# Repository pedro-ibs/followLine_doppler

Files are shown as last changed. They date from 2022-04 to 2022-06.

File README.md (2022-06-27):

# followLine_doppler
Robô seguidor de linha doppler  utilizado na competição "RMS CHALLENGE" 04/21-23 de 2022

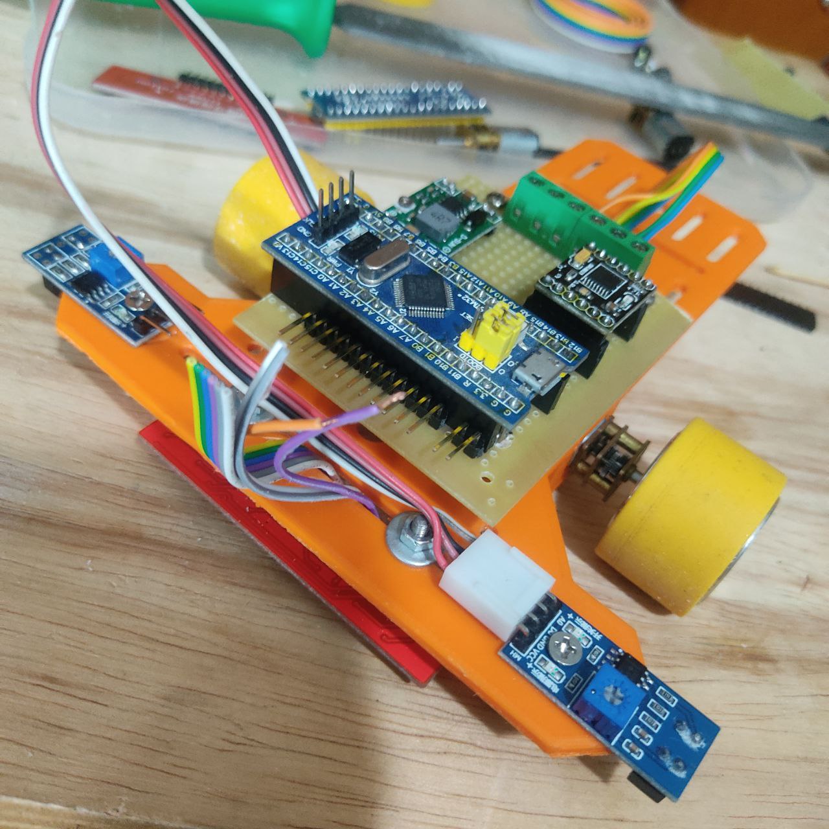
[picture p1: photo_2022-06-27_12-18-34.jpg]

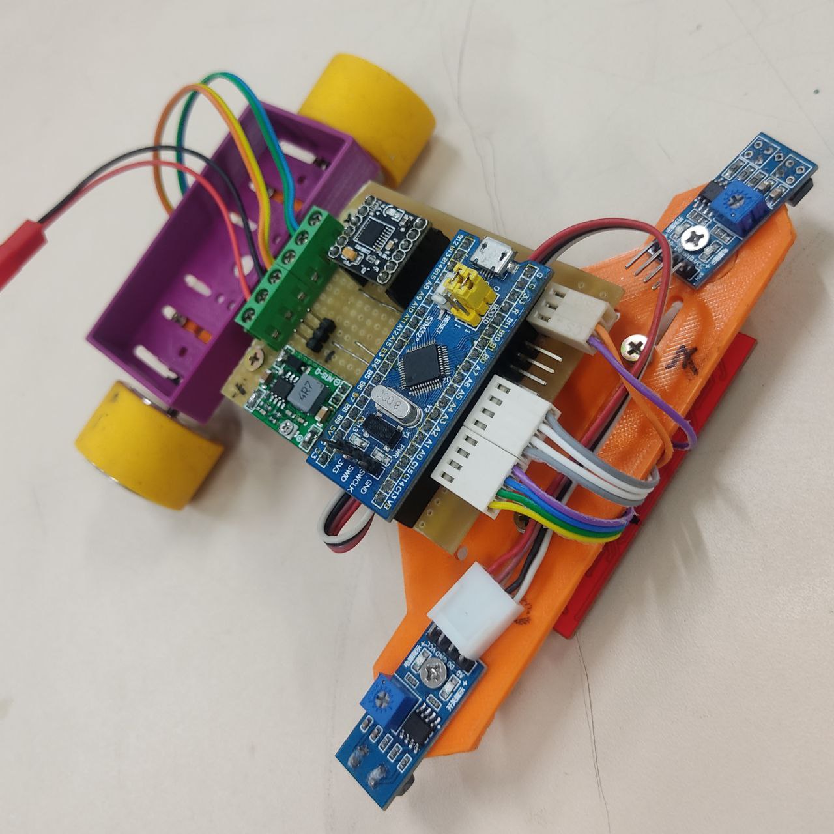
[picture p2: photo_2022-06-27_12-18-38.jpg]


Ele faz uso de um mico controlador stm32f103x na plataforma de desenvolvimento *"bluepill"*. NO  desenvolvimento da firmware foi utilizado o C e o Sistema operacional em tempo real FreeRTOS.

Ela é composta por alguns arquivos importante para a lógica de funcionamento do robô:

<br>

[hardware.h](/firmware/include/hardware.h) Onde são definidos os pinos utilizados, como GPIOs, ADCs etc... 

<br>

[config.h](/firmware/include/config.h) Onde estão configurações globais, como Kp Ki e Kd dos PIDs, valores de cortes das leituras dos ADCs e temporizadores utilizados.

<br>

[pid.h](/firmware/lib/core/FreeRTOS/utility/pid.h) e [pid.c](/firmware/lib/core/FreeRTOS/utility/pid.c), biblioteca para processar o PID, ela abstrai os cálculos do processo. 

<br>

[/motor.h](/firmware/lib/motor/motor.h) e [motor.c](/firmware/lib/motor/motor.c), biblioteca para controle dos motores para pontes H que operam de foram similar ou igual ao LM293D .

<br>

[main_app.c](/firmware/src/main_app.c) Onde a logica de controle ocorre.

## **Funcionamento**

O FreeRTOS é um sistema que opera na vase do tempo e cria treads/tasks para executar as tarefas da aplicação. no caso do robo está sendo utilizado apenas a task principal.

### **Base**

Para realizar as leituras dos sensores cujo o sinal é analógico é utilizado em conjunto o TIMER3, DMA  e os ADCs. Basicamente o sistema realiza aquisições cíclicas em uma taxa de 10kHz por canal, ou seja a cada 0.0001s é realizada a leitura de 8 canais.

As leituras são concluídas após o buffer de memoria alocado estiver cheio, cada canal possui 10 espaços, onde o DMA transfere os valores  lidos do canal para a memoria de forma sequencial. Isso deixa o ciclo completo de leitura dos senores ter 1kHz.

A pós a conclusão das leituras uma interrupção é chamada ( função `void acd1_vBufferDoneHandler(BaseType_t *const pxHigherPriorityTaskWoken)` ), e nela e tratado dodo os cálculos para controlar o robo, isso ocorre de forma cíclica.

<br>

### **Logica de Controle**

**`void main_vApp(void * pvParameters)`**: Onde é inicializado as variáveis e configurado os GPIOs e os periféricos utilizados nas leituras dos sensores e logica da firmware.

**`acd1_vBufferDoneHandler(BaseType_t *const pxHigherPriorityTaskWoken)`**: Onde ocorre as demais etapas do calculo e controle do robô, (NOTA: geralmente essas atividades não ocorrem em interrupções) esse processos são subdivididos em algumas etapas:
  * Limpar variáveis: "`void app_vCleanValues(void)`"
  * Tratamento do sinal: "`void app_vSignalTreatment(void)`"
  * Processamento onde o controle do robo e caculos do pid são executados: "`void app_vProcess(void)`"

**void app_vSignalTreatment(void)**: 

1. Após o DMA concluir o preenchimento do buffer, os dado são acumulados (somados) para cada canal respectivo. Iniciando o processo para calcular do valor médio lido por cada senor (meia móvel).

2. Termino do processo do calculo de media.

3. Transforma os valores lidos pelos sensores em posicionamento onde variam de 0 a 7000 e gradações aproximando se do conceito de uma régua como mostrado abaixo e cada led foto snivel do sensor de linha corresponde a um pondo de S0 a S7:

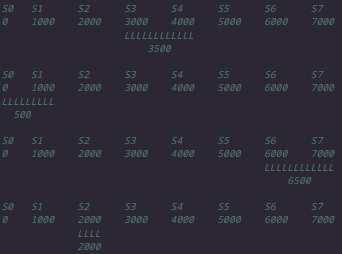
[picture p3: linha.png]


**void app_vProcess(void)**: (documentando, embora haja vários comentários no corpo dessa função )

### **Sobre a mecânica**

O chassi foi feito dessa forma opara permitir alterar a posição dos motores, pois isso afeta no controle do robô quando mais proximo dos pontos de apoio ( roda esférica ) menos força eles terão que fazer para controlar o seguidor, portando ele sera mais rápido assim tendo uma controlei PID mais instável, quando mais longe dos ponto de apoio terá efeito contrario.

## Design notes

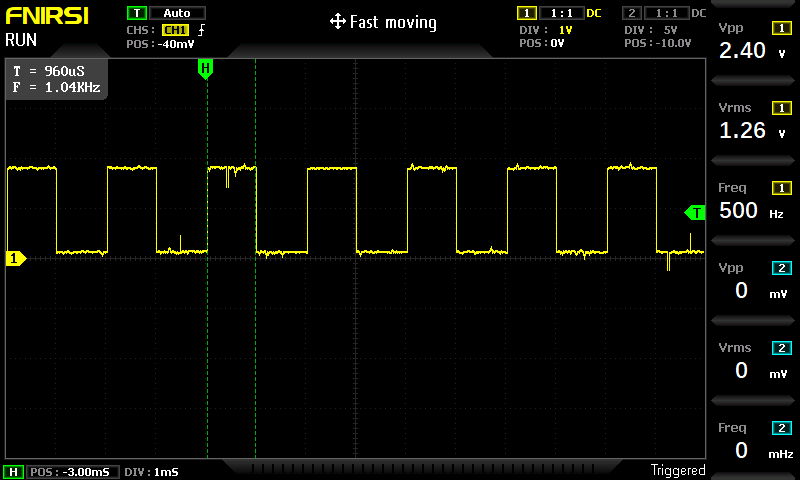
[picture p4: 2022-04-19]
firmware/imd/comCalculos.bmp

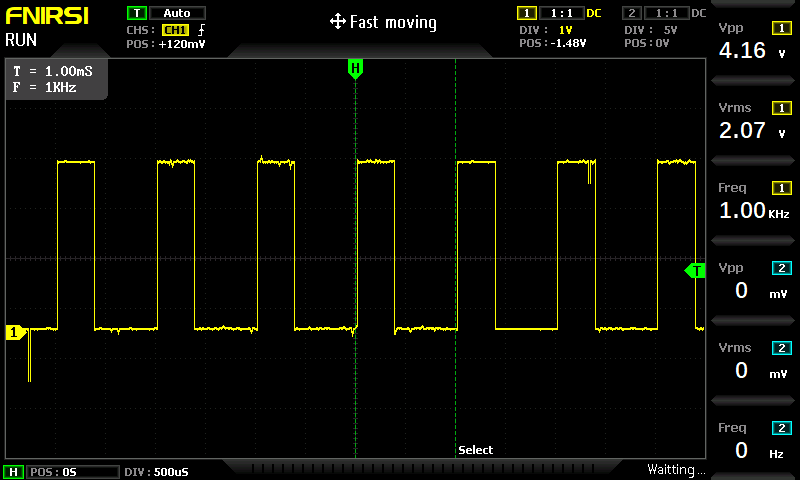
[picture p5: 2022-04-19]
firmware/imd/pwm.bmp

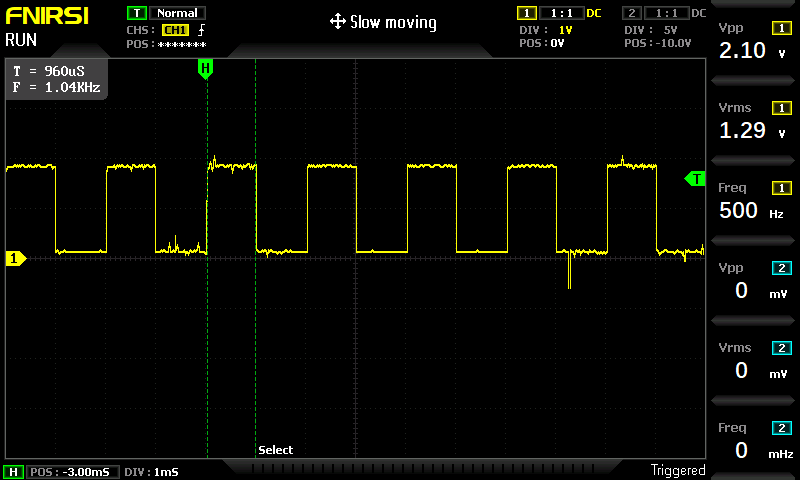
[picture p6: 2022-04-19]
firmware/imd/semCalculos.bmp

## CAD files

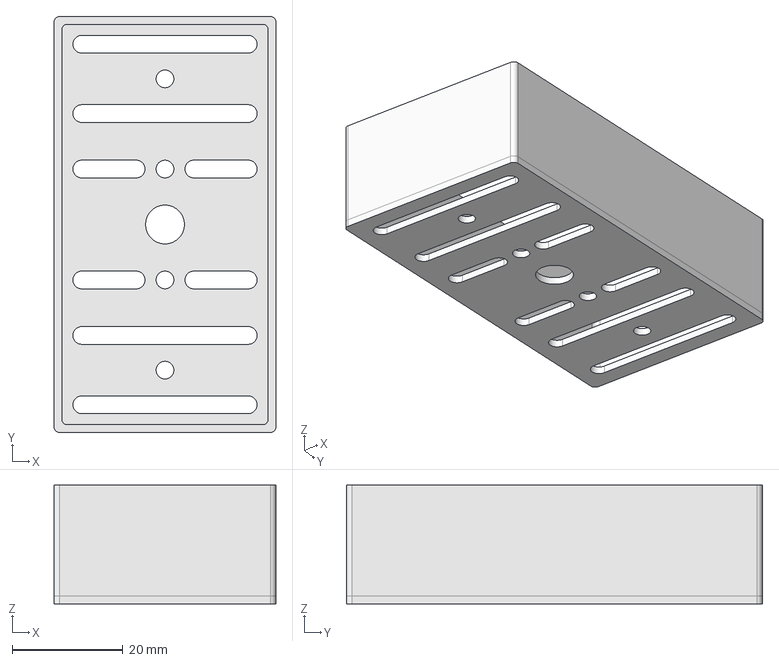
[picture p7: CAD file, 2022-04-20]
freecad/batterySupport.FCStd
40.0 x 75.0 x 21.4 mm

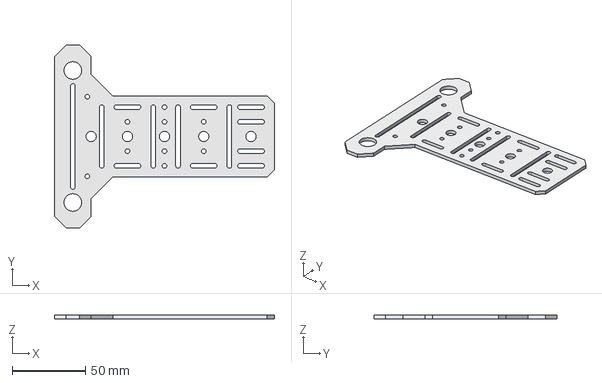
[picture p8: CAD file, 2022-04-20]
freecad/chassi.FCStd
150.0 x 125.0 x 2.50 mm

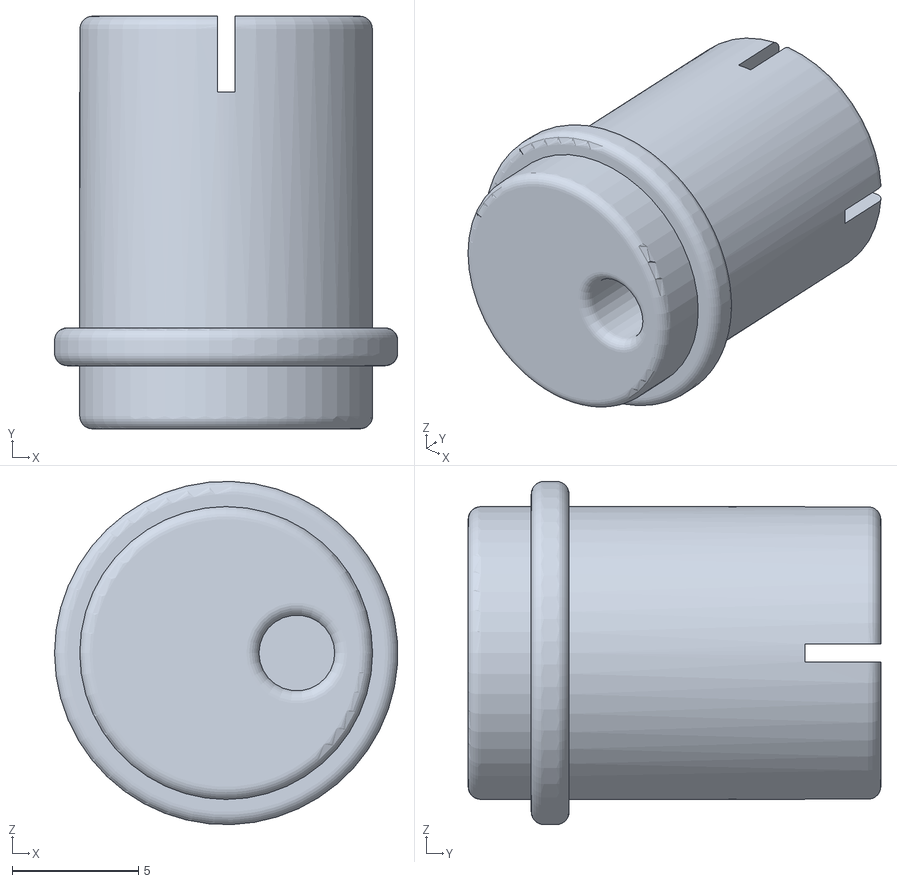
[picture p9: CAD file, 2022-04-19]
freecad/stl/sphericalWheelSupport-Body.stl
13.6 x 16.4 x 13.6

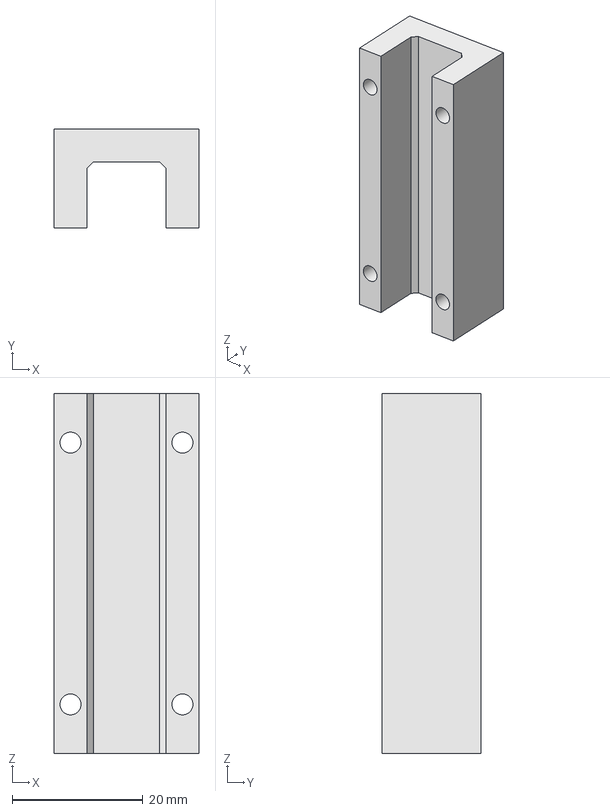
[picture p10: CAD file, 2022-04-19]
freecad/motorFixation.FCStd
22.1 x 15.1 x 55.0 mm

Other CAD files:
freecad/stl/batterySupport-Body.stl
freecad/sphericalWheelSupport.FCStd
freecad/stl/chassi-Body.stl
freecad/stl/motorFixation-Body.stl

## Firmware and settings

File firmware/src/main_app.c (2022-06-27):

/**
 * main_app.h
 *
 *  @date Created at:	13/04/2022 19:30:36
 *	@author:	Pedro Igor B. S.
 *	@email:		pedro.igor.ifsp@gmail.com
 * 	GitHub:		https://github.com/pedro-ibs
 * 	tabSize:	8
 *
 * #######################################################################
 *
 *   Copyright (C) Pedro Igor B. S 2021
 * -------------------------------------------------------------------
 *
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
 * Esse é um programa dedicado ao controle do robô seguidor de linha doppler
 * utilizado na competição "RMS CHALLENGE" 04/21-23 de 2022
 * 
 * A aplicação utiliza o FreeRTOS e drivers para ter acesso aos recursos
 * da CPU
 * 
 * Para a litura dos sensores é utilizado o DMA
 * Para a execução do controle PID e atuação dos motores é utilizado a
 * interrupção do DMA
 * 
 * Em config.h e hardware.h estão as definições de hardware e configurações
 * da aplicação 
 * 
 */



/* Includes ---------------------------------------------------------------------------------------------------------------------------------------------*/
#include <core.h>
#include <FreeRTOS/includes.h>
#include <config.h>
#include <hardware.h>
#include <motor.h>
/* Local macro ------------------------------------------------------------------------------------------------------------------------------------------*/
#define LINE_FULL_DETECTED	(spuAverage[0] < scpuLineDetected[0]) && (spuAverage[7] < scpuLineDetected[7])
/* Local variables --------------------------------------------------------------------------------------------------------------------------------------*/
typedef struct {
	Motor xMotor;
	float fPwm;
}MotorTask;

static const u16 scpuLineDetected[SAMPLES]	= {
	LINE_DETECTED_0,
	LINE_DETECTED_1,
	LINE_DETECTED_2,
	LINE_DETECTED_3,
	LINE_DETECTED_4,
	LINE_DETECTED_5,
	LINE_DETECTED_6,
	LINE_DETECTED_7
};

static const short int scpuLineValue[SAMPLES]	= {
	LINE_VALUE_0,
	LINE_VALUE_1,
	LINE_VALUE_2,
	LINE_VALUE_3,
	LINE_VALUE_4,
	LINE_VALUE_5,
	LINE_VALUE_6,
	LINE_VALUE_7
};

static u16 spuAdc1Buffer[BUFFER_SIZE]		= { 0 };
static u16 spuAverage[CHANNELS]			= { 0 };
static MotorTask sxMa 				= { { MOTOR_M1A1_PWM, MOTOR_M1A2_PWM }, PWM_MIN };
static MotorTask sxMb 				= { { MOTOR_M2A1_PWM, MOTOR_M2A2_PWM }, PWM_MIN };
static Pid sxPid				= { 0 };
static u16 uPosition				= 0;
static TickType_t sxIgnoreStop			= 0;
static TickType_t sxToStop			= 0;

/* Local Functions --------------------------------------------------------------------------------------------------------------------------------------*/
void motor_vTask(void * pvParameters);
void app_vSignalTreatment(void);
void app_vCleanValues( void );
void app_vProcess( void );
/* Functions --------------------------------------------------------------------------------------------------------------------------------------------*/


/*########################################################################################################################################################*/
/*########################################################################################################################################################*/
/*########################################################################################################################################################*/
/*-------------------------------------------------------------------- Local Functions -------------------------------------------------------------------*/
/*########################################################################################################################################################*/

/**
 * Apos as configurações de hardware e valores de variáveis, Essa só irá  task existir
 * para realizar o "debug", caso APP_DEBUG não for definido ela será desativada (deletada).
 * 
 * veja em platformio.ini
 */
void main_vApp(void * pvParameters){
	(void) pvParameters;

	vTaskDelay(_5S);

	sxPid.fSetPoint = PID_SETPOINT;
	sxPid.fKp 	= PID_KP;
	sxPid.fKi 	= PID_KI;
	sxPid.fKd 	= PID_KD;


	/**
	 * ignora o stop na partida por 10 segundos já na partida há um cursamento 
	 * evitando que o robô pare logo no inicio
	 */
	sxIgnoreStop	= 10000;

	gpio_vInitAll(  );
	gpio_vDisableDebug ( );

	gpio_vMode( LED,	GPIO_MODE_OUTPUT_OD,	GPIO_PULLDOWN );
	gpio_vMode( LINE_STOP,	GPIO_MODE_INPUT,	GPIO_PULLDOWN );
	gpio_vMode( LINE_CURVE,	GPIO_MODE_INPUT,	GPIO_PULLDOWN );

	pwm_vSetGpio( MOTOR_M1A1 );
	pwm_vSetGpio( MOTOR_M1A2 );
	pwm_vSetGpio( MOTOR_M2A1 );
	pwm_vSetGpio( MOTOR_M2A2 );

	
	pwm_vSetup( TIM1, PWM_PRESCALER, PWM_PERIOD );
	motor_vToStop( PWM_MAX, &sxMa.xMotor );
	motor_vToStop( PWM_MAX, &sxMb.xMotor );

	adc1_vInit();
	adc1_vSetGetSampleMode( CHANNELS );
	adc1_vSetChannel( LINE_0, ADC_SAMPLETIME, ADC_REGULAR_RANK_1	);
	adc1_vSetChannel( LINE_1, ADC_SAMPLETIME, ADC_REGULAR_RANK_2	);
	adc1_vSetChannel( LINE_2, ADC_SAMPLETIME, ADC_REGULAR_RANK_3	);
	adc1_vSetChannel( LINE_3, ADC_SAMPLETIME, ADC_REGULAR_RANK_4	);
	adc1_vSetChannel( LINE_4, ADC_SAMPLETIME, ADC_REGULAR_RANK_5	);
	adc1_vSetChannel( LINE_5, ADC_SAMPLETIME, ADC_REGULAR_RANK_6	);
	adc1_vSetChannel( LINE_6, ADC_SAMPLETIME, ADC_REGULAR_RANK_7	);
	adc1_vSetChannel( LINE_7, ADC_SAMPLETIME, ADC_REGULAR_RANK_8	);


	/**
	 * A frequência de aquisição é de 10kHz, onde os
	 * canais são lidos 10 vezes antes de chamar a
	 * interrupção do DAM dessa forma ela irá ocorrer
	 * a cada 1ms  (1kHz).
	 */
	adc1_vStartGetSampleMode( spuAdc1Buffer, BUFFER_SIZE, PRESCALER, PERIOD );


	#ifdef APP_DEBUG
		char pcString[10] = "0";
	#endif

	while (TRUE) {
		#ifdef APP_DEBUG
			usart_vAtomicSendStr(ttyUSART1, "MA: ");
			usart_vAtomicSendStr(ttyUSART1, textp_pcCharLeft(itoa(sxPid.fSetPoint,	pcString, DEC), 4, ' '));
			usart_vAtomicSendStr(ttyUSART1, ", ");
			usart_vAtomicSendStr(ttyUSART1, textp_pcCharLeft(itoa(uPosition,	pcString, DEC), 4, ' '));
			usart_vAtomicSendStr(ttyUSART1, ", ");
			usart_vAtomicSendStr(ttyUSART1, textp_pcCharLeft(itoa(sxPid.fError,	pcString, DEC), 4, ' '));
			usart_vAtomicSendStr(ttyUSART1, ", ");
			usart_vAtomicSendStr(ttyUSART1, textp_pcCharLeft(itoa(sxPid.fOutput,	pcString, DEC), 4, ' '));
			usart_vAtomicSendStr(ttyUSART1, ", ");
			usart_vAtomicSendStr(ttyUSART1, textp_pcCharLeft(itoa(sxMa.fPwm,	pcString, DEC), 4, ' '));
			usart_vAtomicSendStr(ttyUSART1, ", ");
			usart_vAtomicSendStr(ttyUSART1, textp_pcCharLeft(itoa(sxMb.fPwm,	pcString, DEC), 4, ' '));
			usart_vAtomicSendStr(ttyUSART1, "\r\n" );
		#else
			break;
		#endif

		/**
		 * esse delay é necessário para evitar starvation
		 */
		vTaskDelay(_20MS);
	}

	vTaskDelete(NULL);
}


void app_vCleanValues( void ){
	for (u8 uChannel = 0; uChannel < CHANNELS; uChannel++) {
		spuAverage[uChannel] = 0;
	}
	uPosition = 0;
}

/**
 * 1 ) Após o DMA concluir o preenchimento do buffer, os dado
 * são acumulados (somados) para cada canal respectivo.
 * iniciando o processo para calcular do valor médio lido por
 * cada senor.
 * 
 * 2 ) Termino do processo do calculo de media.
 * 
 * 3 ) Transforma os valores lidos pelos sensores em posicionamento
 * onde variam de 0 a 7000 e gradações como mostrado abaixo:
 * 
 * 
 * S0	S1	S2	S3	S4	S5	S6	S7
 * 0	1000	2000	3000	4000	5000	6000	7000
 * 			LLLLLLLLLLLL
 * 			    3500
 * 
 * S0	S1	S2	S3	S4	S5	S6	S7
 * 0	1000	2000	3000	4000	5000	6000	7000
 * LLLLLLLLL
 *   500
 * 
 * S0	S1	S2	S3	S4	S5	S6	S7
 * 0	1000	2000	3000	4000	5000	6000	7000
 * 						LLLLLLLLLLLL
 * 						    6500
 * 
 * S0	S1	S2	S3	S4	S5	S6	S7
 * 0	1000	2000	3000	4000	5000	6000	7000
 *		LLLL
 *		2000
 */
void app_vSignalTreatment( void ){
	for (u8 uSample = 0; uSample < SAMPLES; uSample++) {
		for (u8 uChannel = 0; uChannel < CHANNELS; uChannel++) {
			spuAverage[uChannel] += spuAdc1Buffer[ ( uSample * CHANNELS ) + uChannel ];
		}
	}

	for (u8 uChannel = 0; uChannel < CHANNELS; uChannel++) {
		spuAverage[uChannel] = (spuAverage[uChannel] / SAMPLES );
	}

	u8 uContDetection = 0;
	for (u8 uChannel = 0; uChannel < CHANNELS; uChannel++) {
		if(spuAverage[uChannel] < scpuLineDetected[uChannel]){
			uContDetection++;

			/**
			 * Manter Valor máximo detectado
			 */
			uPosition = ( scpuLineValue[uChannel]  );

			/**
			 * Criar gradação intermediaria
			 */
			if(uContDetection > 1){
				uPosition -= ( LINE_VALUE_1 / 2 );
			}
		};
	}
}


void app_vProcess( void ){

	/**
	 * após a detecção da linha de chegada o robô irá parara 
	 * apos um certo período de tempo, fazendo com que o mesmo
	 * pere após a linha de chegada.  
	 */
	if(sxToStop > 0){
		/**
		 * O overchute do controle pode fazer com que o robô
		 * trave em cima de um cruzamento para evitar isso é 
		 * verificado se a fixa está embaixo do sensor 
		 */
		if( ( LINE_FULL_DETECTED ) == TRUE ){
			sxToStop = 0;
		}

		/**
		 * indica que o robô está travado 
		 */
		gpio_vWrite(LED, FALSE);


		if( xTaskGetTickCountFromISR() > sxToStop ){
			sxMa.fPwm = PWM_MAX;
			sxMb.fPwm = PWM_MAX;	

			motor_vToStop(sxMa.fPwm, &sxMa.xMotor);
			motor_vToStop(sxMb.fPwm, &sxMb.xMotor);

			return;
		}

	}

	/**
	 * Se todos os sensores estão ativos o robô está
	 * em um cruzamento portanto o stop deve ser ignorado
	 * por um tempo, e o robô deve continuar indo para
	 * frente.
	 */
	if( LINE_FULL_DETECTED ){
		sxIgnoreStop	= xTaskGetTickCountFromISR() + IGNORE_STOP;
		sxToStop	= 0;
		sxMa.fPwm 	= PWM_OFFSET;
		sxMb.fPwm 	= PWM_OFFSET;	

		motor_vToFront(sxMa.fPwm, &sxMa.xMotor);
		motor_vToFront(sxMb.fPwm, &sxMb.xMotor);

		return;
	}
	
	/**
	 * Quando faixa de chagada for detectada o robô
	 * iár travar os motores e "desabilitar/ignorar" 
	 * o controle pid PID, pro meio de um "ponto de
	 * fuga" no inicio da função.
	 */
	if(sxIgnoreStop < xTaskGetTickCountFromISR()){
		if(gpio_bRead(LINE_STOP) == FALSE){
			sxToStop	= WAIT_TO_STOP + xTaskGetTickCountFromISR();
			return;
		}
	}


	/**
	 * Entrada do controle PID
	 */
	sxPid.fInput = uPosition;
	sxPid.fOutput =  pid_fRunFromISR(&sxPid);

	if(uPosition < PID_SETPOINT){
		sxMa.fPwm = PWM_OFFSET + abs(sxPid.fOutput);
		sxMb.fPwm = PWM_OFFSET - abs(sxPid.fOutput);
	} else if(uPosition > PID_SETPOINT){
		sxMa.fPwm = PWM_OFFSET - abs(sxPid.fOutput);
		sxMb.fPwm = PWM_OFFSET + abs(sxPid.fOutput);
	} else {
		sxMa.fPwm = PWM_OFFSET;
		sxMb.fPwm = PWM_OFFSET;
	}


	/**
	 * Tratar valores do PWM para evitar que ultrapasse
	 * o limite configurado no periférico
	 */
	if(sxMa.fPwm > PWM_MAX ){
		sxMa.fPwm = PWM_MAX;	
	}

	if(sxMa.fPwm < PWM_MIN ){
		sxMa.fPwm = PWM_MIN;	
	}

	if(sxMb.fPwm > PWM_MAX ){
		sxMb.fPwm = PWM_MAX;	
	}

	if(sxMb.fPwm < PWM_MIN ){
		sxMb.fPwm = PWM_MIN;	
	}

	/**
	 * ! CONTROLE ON OFF
	 * Os sensores mais extremos ( S0, S7 ) estão atrelados ao  controle
	 * ON OFF isso foi utilizado para evitar que o robô perdesse a linha
	 * em uma curva.
	 * 
	 * Os outros senhores  S1, S2, S3, S4, S5, S6 foram mantido no controle
	 * PID, porem esse controle é ignorado quando o ON OFF está ativo
	 */
	if( (spuAverage[0] < scpuLineDetected[0]) ){
		sxMa.fPwm = PWM_MAX;
		sxMb.fPwm = PWM_MAX;
		motor_vToFront(sxMa.fPwm, &sxMa.xMotor);
		motor_vToStop(sxMb.fPwm, &sxMb.xMotor);
		return;
	}

	if( (spuAverage[7] < scpuLineDetected[7]) ){
		sxMa.fPwm = PWM_MAX;
		sxMb.fPwm = PWM_MAX;
		motor_vToStop(sxMa.fPwm, &sxMa.xMotor);
		motor_vToFront(sxMb.fPwm, &sxMb.xMotor);
		return;
	}

	/**
	 * Isso é apenas um recurso para facilitar nos testes em uma pista.
	 * ao perder a linha completamente o motores são desligados
	 */
	if (uPosition == 0){
		if((spuAverage[0] < scpuLineDetected[0]) == FALSE){
			motor_vTurnoff(&sxMa.xMotor);
			motor_vTurnoff(&sxMb.xMotor);
			return;
		}
	}


	motor_vToFront(sxMa.fPwm, &sxMa.xMotor);
	motor_vToFront(sxMb.fPwm, &sxMb.xMotor);
}

void acd1_vBufferDoneHandler(BaseType_t *const pxHigherPriorityTaskWoken){
	(void) pxHigherPriorityTaskWoken;

	app_vCleanValues();

	app_vSignalTreatment();

	app_vProcess();

	gpio_vToggle(LED);
}


void adc1_vDMA1Ch1Handler(BaseType_t *const pxHigherPriorityTaskWoken){
	(void) pxHigherPriorityTaskWoken;
}

void tim3_vHandler(BaseType_t *const pxHigherPriorityTaskWoken){
	(void) pxHigherPriorityTaskWoken;

}

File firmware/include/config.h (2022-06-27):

/**
 * config.h
 *
 *  @date Created at:	13/04/2022 19:27:34
 *	@author:	Pedro Igor B. S.
 *	@email:		pedro.igor.ifsp@gmail.com
 * 	GitHub:		https://github.com/pedro-ibs
 * 	tabSize:	8
 *
 * #######################################################################
 *
 *   Copyright (C) Pedro Igor B. S 2021
 * -------------------------------------------------------------------
 *
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
 *
 * configurações da aplicação
 *
 */

/* Includes ---------------------------------------------------------------------------------------------------------------------------------------------*/
#include "hardware.h"
#include "FreeRTOS/include/FreeRTOSConfig.h"

#ifndef config_H_
#define config_H_

/* macro -------------------------------------------------------------------------------------------------------------------------------------------------*/
/* Definition --------------------------------------------------------------------------------------------------------------------------------------------*/


/*--------------------------------------------------------------------------------------------------------------------------------------------------------*/
/* Configuração para aquisição e tratamento dos sinais analógicos											  */
/*--------------------------------------------------------------------------------------------------------------------------------------------------------*/
#define CHANNELS			( 8							)
#define SAMPLES				( 10 							)
#define BUFFER_SIZE			( CHANNELS * SAMPLES 					)


#define FREQUENCY			( 1000							)
#define PRESCALER			( 1							)
#define PERIOD				( FREG_TO_COUNTER( FREQUENCY*SAMPLES, PRESCALER )	)
#define ADC_SAMPLETIME			( ADC_SAMPLETIME_71CYCLES_5				)

#define LINE_DETECTED_0			( 3500							)
#define LINE_DETECTED_1			( 3500							)
#define LINE_DETECTED_2			( 3500							)
#define LINE_DETECTED_3			( 3500							)
#define LINE_DETECTED_4			( 3500							)
#define LINE_DETECTED_5			( 3500							)
#define LINE_DETECTED_6			( 3500							)
#define LINE_DETECTED_7			( 3500							)


#define LINE_VALUE_0			( 1000 * 0						)
#define LINE_VALUE_1			( 1000 * 1						)
#define LINE_VALUE_2			( 1000 * 2						)
#define LINE_VALUE_3			( 1000 * 3						)
#define LINE_VALUE_4			( 1000 * 4						)
#define LINE_VALUE_5			( 1000 * 5						)
#define LINE_VALUE_6			( 1000 * 6						)
#define LINE_VALUE_7			( 1000 * 7						)



/*--------------------------------------------------------------------------------------------------------------------------------------------------------*/
/* Configuração para controle de valosidade														  */
/*--------------------------------------------------------------------------------------------------------------------------------------------------------*/
#define PWM_PRESCALER			( 72-1							)
#define PWM_PERIOD			( 1000-1						)
#define PWM_MAX				( 1000							)
#define PWM_MIN				( 0							)
#define PWM_OFFSET			( PWM_MAX * 0.75					)


#define PID_KP				( 0.75							)
#define PID_KI				( 0.01							)
#define PID_KD				( 0.075							)
#define PID_SETPOINT			( LINE_VALUE_4 - ( LINE_VALUE_1 / 2 )			)


/*--------------------------------------------------------------------------------------------------------------------------------------------------------*/
/* Configuração ferais de tempo																  */
/*--------------------------------------------------------------------------------------------------------------------------------------------------------*/
#define IGNORE_STOP			( 1000 							)
#define WAIT_TO_STOP			( 1000							)

#endif /* config_H_ */

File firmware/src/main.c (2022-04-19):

/**
 * main.c.c
 *
 *  @date Created at:	13/07/2021 13:19:19
 *	@author:	Pedro Igor B. S.
 *	@email:		pibscontato@gmail.com
 * 	GitHub:		https://github.com/pedro-ibs
 * 	tabSize:	8
 *
 * #################################################################################
 * 
 * FreeRTOS Kernel V10.2.1
 * Copyright (C) 2019 Amazon.com, Inc. or its affiliates.  All Rights Reserved.
 *
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
 * http://www.FreeRTOS.org
 * http://aws.amazon.com/freertos
 *
 * 1 tab == 8 spaces!
 * 
 * #################################################################################
 *
 * comtem os handlres do FreeRTOS e inicia o sistema operacionão e deus drivers  e a
 * task principal da aplicação
 *
 */



/* Includes ---------------------------------------------------------------------------------------------------------------------------------------------*/
/* Standard includes. */
#include <string.h>
#include <stdio.h>
#include <stdint.h>
#include <stdlib.h>

/* stm standard includes.  */
#include <core.h>


/* FreeRTOS standard includes.  */
#include <FreeRTOS/includes.h>

/* Private macro ----------------------------------------------------------------------------------------------------------------------------------------*/
/* Private variables ------------------------------------------------------------------------------------------------------------------------------------*/
/* Private Functions ------------------------------------------------------------------------------------------------------------------------------------*/
static void svSetup( void );
static void svSystemClockConfig(void);
static void svAppMainInit(void * pvParameters);
/* Functions --------------------------------------------------------------------------------------------------------------------------------------------*/


int main( void ) {
	#ifdef DEBUG
	debug();
	#endif

	vTaskSuspendAll();
	
	svSetup();
	
	if( xTaskCreate( svAppMainInit, "app_init", configAPP_MAIN_STACK, NULL, tskIDLE_PRIORITY, NULL ) != pdPASS){
		NVIC_SystemReset();
	}

	xTaskResumeAll();

	/* Start the scheduler. */
	vTaskStartScheduler();

	/**
	 * Will only get here if there was insufficient memory to create the idle
	 * task.  The idle task is created within vTaskStartScheduler().
	 */
	for( ;; );

	return 0;
}

/*########################################################################################################################################################*/
/*########################################################################################################################################################*/
/*########################################################################################################################################################*/
/*-------------------------------------------------------------------- Private Functions -----------------------------------------------------------------*/
/*########################################################################################################################################################*/


/**
 * @brief configuração base hardware do microcontrolador 
 * e clock
 */
static void svSetup( void ) {
	SystemCoreClockUpdate();
	HAL_Init();
	svSystemClockConfig();
	HAL_RCC_EnableCSS();

	// FLASH_OB_Unlock();
	// FLASH_OB_RDPConfig( OB_RDP_Level_1 );
	// if (FLASH_OB_Launch() != FLASH_COMPLETE)
	// {
	//     err_printf("Error enabling RDP\n");
	// }
	// FLASH_OB_Lock();
}

void svSystemClockConfig(void) {
	
	/**
	 * Initializes the RCC Oscillators according to the specified parameters
	 * in the RCC_OscInitTypeDef structure.
	 */
	RCC_OscInitTypeDef RCC_OscInitStruct 	= {0};
	RCC_OscInitStruct.OscillatorType	= RCC_OSCILLATORTYPE_LSI|RCC_OSCILLATORTYPE_HSE;
	RCC_OscInitStruct.HSEState		= RCC_HSE_ON;
	RCC_OscInitStruct.HSEPredivValue	= RCC_HSE_PREDIV_DIV1;
	RCC_OscInitStruct.HSIState		= RCC_HSI_ON;
	RCC_OscInitStruct.LSIState		= RCC_LSI_ON;
	RCC_OscInitStruct.PLL.PLLState		= RCC_PLL_ON;
	RCC_OscInitStruct.PLL.PLLSource		= RCC_PLLSOURCE_HSE;
	RCC_OscInitStruct.PLL.PLLMUL		= RCC_PLL_MUL9;
	if (HAL_RCC_OscConfig(&RCC_OscInitStruct) != HAL_OK) {
		Error_Handler();
	}

	/**
	 * Initializes the CPU, AHB and APB buses clocks
	 */
	RCC_ClkInitTypeDef RCC_ClkInitStruct	= {0};
	RCC_ClkInitStruct.ClockType		= RCC_CLOCKTYPE_HCLK|RCC_CLOCKTYPE_SYSCLK|RCC_CLOCKTYPE_PCLK1|RCC_CLOCKTYPE_PCLK2;
	RCC_ClkInitStruct.SYSCLKSource		= RCC_SYSCLKSOURCE_PLLCLK;
	RCC_ClkInitStruct.AHBCLKDivider		= RCC_SYSCLK_DIV1;
	RCC_ClkInitStruct.APB1CLKDivider	= RCC_HCLK_DIV2;
	RCC_ClkInitStruct.APB2CLKDivider	= RCC_HCLK_DIV1;
	if (HAL_RCC_ClockConfig(&RCC_ClkInitStruct, FLASH_LATENCY_2) != HAL_OK){
		Error_Handler();
	}
	
	/**
	 * Ativa o RCC do RTC
	 * Configurar o Clock do ADC1 em 12Mhz
	 */
	RCC_PeriphCLKInitTypeDef PeriphClkInit = {0};
	PeriphClkInit.PeriphClockSelection 		= RCC_PERIPHCLK_RTC|RCC_PERIPHCLK_ADC;
	PeriphClkInit.RTCClockSelection			= RCC_RTCCLKSOURCE_LSI;
	PeriphClkInit.AdcClockSelection 		= RCC_ADCPCLK2_DIV6;
	if (HAL_RCCEx_PeriphCLKConfig(&PeriphClkInit) != HAL_OK) {
		Error_Handler();
	}

}


/**
 * @brief pré inicia drivers de uso geral 
 * 
 */
static void svAppMainInit(void * pvParameters){
	(void) pvParameters;
	
	rtc_vInit();

	iwdg_vInit();

	flash_vInit();

	gpio_vInitAll();

	adc1_vInit();

	swap_vSetup();

	#ifndef DEBUG
	gpio_vDisableDebug();
	#endif

	usart_vSetup(ttyUSART1, usart_19k2bps);

	vTaskDelay(_200MS);
	
	#ifdef APP_DEBUG
	usart_vAtomicSendStrLn(ttyUSART1, "\r\nFreeRTOS Started!");
	#endif

	if( xTaskCreate( main_vApp, "app_main", configAPP_MAIN_STACK, NULL, tskIDLE_PRIORITY, NULL ) != pdPASS){
		NVIC_SystemReset();
	}

	vTaskDelete(NULL);
}
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

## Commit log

2022-04-19 doppler 1.0
    [fixador-Body001.stl, fixador.FCStd, rodaEsferica-Body.stl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]
2022-04-19 update doc and PID
2022-04-19 update pid
2022-04-20 arrumando peças 3Ds
    [batterySupport-Body.stl, batterySupport.FCStd, chassi-Body.stl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]
2022-04-22 alterações necessárias para o robo não perder a linha
2022-04-22 aviso de documentação

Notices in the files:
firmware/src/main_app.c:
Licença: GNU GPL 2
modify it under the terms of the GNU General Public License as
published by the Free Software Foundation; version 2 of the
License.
